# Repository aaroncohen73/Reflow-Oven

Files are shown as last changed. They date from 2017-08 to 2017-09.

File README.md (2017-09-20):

# Code and Design files for Solder Reflow Toaster Oven

The code (available inside `code/`) is licensed under the
[GNU General Public License, version 3](https://www.gnu.org/licenses/gpl.html), and
the PCB design (available inside `design/`) is licensed under the
[Creative Commons ShareAlike 4.0 International](https://creativecommons.org/licenses/by-sa/4.0/) license.

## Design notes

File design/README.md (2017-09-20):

# EAGLE CAD Design Files for Solder Reflow Toaster Oven

This design is compatible with EAGLE 8.2+

This design is licensed under the [Creative Commons ShareAlike 4.0 International](https://creativecommons.org/licenses/by-sa/4.0/) license.

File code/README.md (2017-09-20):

# Code for Solder Reflow Toaster Oven

The code in this subdirectory is available under the [GNU General Public License, version 3](https://www.gnu.org/licenses/gpl.html).

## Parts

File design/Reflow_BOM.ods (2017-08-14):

Reference | Digikey Part Number | Manufacturer | Description | Function
U1 | ATMEGA328-AU-ND | Microchip | ATmega328 Microcontroller, 28DIP | Oven controller
U2 | 768-1135-1-ND | FTDI | FT230XS-R USB to UART bridge, 16SSOP | USB control interface
U3 | LM3940IT-3.3/NOPB-ND | TI | Linear Voltage Regulator, 3.3V, 1A, TO-220 | 3.3V regulator
H1 | S6106-ND | Sullins | Female DIP Header 2x10 | Display cable header
H2 | A123836-ND | TE | 2 Position Screwless Terminal Block | Thermocouple connector
H3 | A123836-ND | TE | 2 Position Screwless Terminal Block | SSR connector
Q1 | IRF9610PBF-ND | Vishay | P-Channel MOSFET, 200V, 1.8A, 20W, TO-220 | Reverse polarity protection
Q2 | 2N7000TACT-ND | ON Semiconductor | N-Channel MOSFET, 60V, 200mA, 400mW, TO-92 | SSR switch
J1 | CP-202B-ND | CUI Inc. | DC Power Barrel Connector, Through Hole | DC power jack
J2 | ED2982-ND | On Shore Technology | USB Type B Connector, Through Hole | USB connector
C1 | 493-12980-1-ND | Nichicon | 0.47uF Electrolytic Capacitor, 200V, Through Hole 5mm | LDO 5V decoupling
C2 | 493-5358-1-ND | Nichicon | 33uF Electrolytic Capacitor, 200V, Through Hole 5mm | LDO 3.3V decoupling
C3 | 493-1826-ND | Nichicon | 470uF Electrolytic Capacitor, 200V, Through Hole 5mm | Display VDD decoupling
C4 | BC1009CT-ND | Vishay | 47pF Capacitor, 50V, Through Hole 5mm | USB D+ noise filter
C5 | BC1009CT-ND | Vishay | 47pF Capacitor, 50V, Through Hole 5mm | USB D- noise filter
R1 | CF14JT4K70CT-ND | Stackpole | 4.7k Resistor, 1/4W, Through Hole 5mm | USB sense voltage divider
R2 | CF14JT10K0CT-ND | Stackpole | 10k Resistor, 1/4W, Through Hole 5mm | USB sense voltage divider
R3 | CF14JT27R0CT-ND | Stackpole | 27 Ohm Resistor, 1/4W, Through Hole 5mm | USB D+ noise filter
R4 | CF14JT27R0CT-ND | Stackpole | 27 Ohm Resistor, 1/4W, Through Hole 5mm | USB D- noise filter
R5 | CF14JT270RCT-ND | Stackpole | 270 Ohm Resistor, 1/4W, Through Hole 5mm | TX LED current limiter
R6 | CF14JT270RCT-ND | Stackpole | 270 Ohm Resistor, 1/4W, Through Hole 5mm | RX LED current limiter
R7 | CF14JT270RCT-ND | Stackpole | 270 Ohm Resistor, 1/4W, Through Hole 5mm | SSR current limiter
R8 | CF14JT270RCT-ND | Stackpole | 270 Ohm Resistor, 1/4W, Through Hole 5mm | Power LED current limiter
D1 | 160-1677-ND | Lite-On | Green LED, 2.1V, Through Hole 5mm | UART TX LED
D2 | 160-1686-ND | Lite-On | Yellow LED, 2.05V, Through Hole 5mm | UART RX LED
D3 | 160-1677-ND | Lite-On | Green LED, 2.1V, Through Hole 5mm | Power LED
FB1 | 240-2378-1-ND | Laird | Ferrite Bead, 1k @ 100MHz, 0603 | Thermocouple noise filter
FB2 | 240-2378-1-ND | Laird | Ferrite Bead, 1k @ 100MHz, 0603 | Thermocouple noise filter
- | 255-2978-ND | Panasonic | AQA221VL Solid State Relay, Screw Terminals | Oven power relay
- | 255-2665-ND | Panasonic | AQP-HS-30/40A Heatsink for Solid State Relay | Relay heatsink
- | NHD-1.69-160128UGC3-ND | Newhaven Display | OLED Display, 160x128, 1.69”, 3-Wire SPI | Status display
- | 1286-1099-ND | Digilent | Thermocouple Type K, 1m | Temperature sensor
- | 1175-1661-ND | CNC Tech | Ribbon Cable Male DIP Header 2x10 | Display cable header
- | 1175-1661-ND | CNC Tech | Ribbon Cable Male DIP Header 2x10 | Display cable header
- | S6106-ND | Sullins | Female DIP Header 2x10 | Display cable header

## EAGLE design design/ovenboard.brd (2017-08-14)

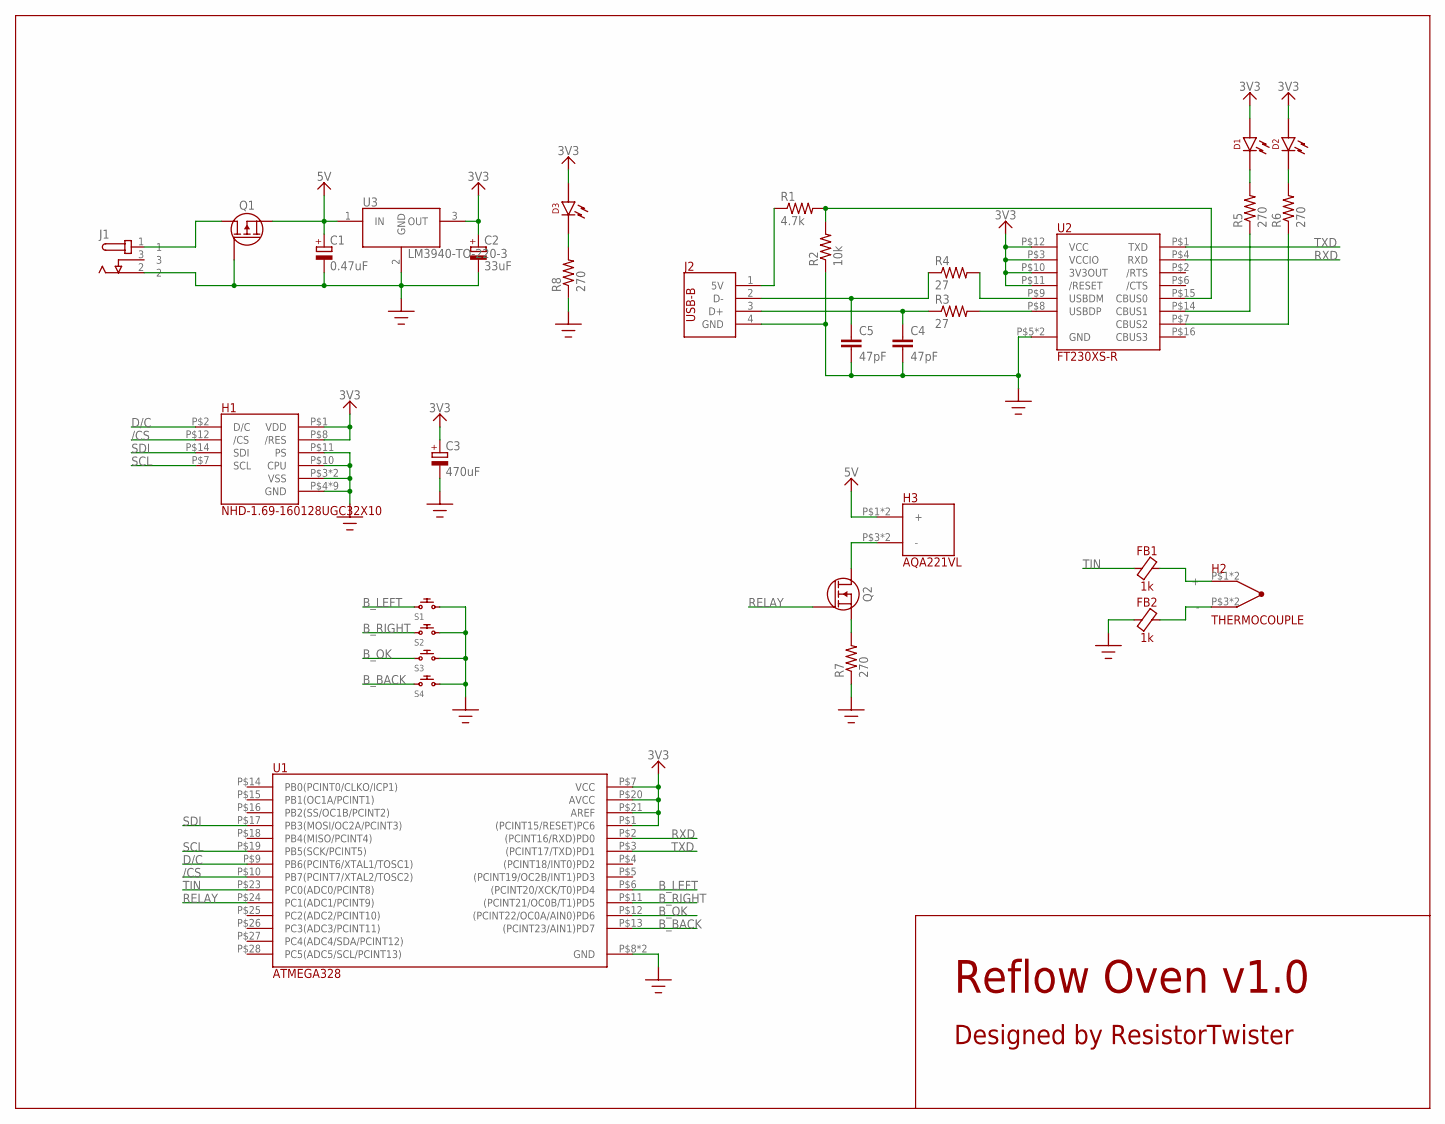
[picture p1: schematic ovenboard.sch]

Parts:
C1: 0.47uF; E5-5
C2: 33uF; E5-5
C3: 470uF; E5-5
C4, C5: 47pF; C050-024X044
D1, D2, D3: LED-5; LED5
FB1, FB2: 1k; 0603
H1: NHD-1.69-160128UGC32X10; 2X10HEADER0.1
H2: THERMOCOUPLE; 2TERMINAL
H3: AQA221VL; 2TERMINAL
J1: PJ-202B
J2: USB2.0-B1HSW6; B1HSW6
Q1: MOSFET-P-TO-220-3; TO-220-3
Q2: MOSFET-N-TO-92; TO-92
R1: 4.7k; 0204/5
R2: 10k; 0204/5
R3, R4: 27; 0204/5
R5, R6, R7, R8: 270; 0204/5
S1, S2, S3, S4: PUSHBUTTON; 1X2HEADER0.1
U1: ATMEGA328; 28DIP0.1
U2: FT230XS-R; 16SSOP0.025
U3: LM3940-TO-220-3; TO-220-3

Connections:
3V3: C2.+, C3.+, D1.A, D2.A, D3.A, H1.P$1 (VDD), H1.P$8 (/RES), U1.P$1 ((PCINT15/RESET)PC6), U1.P$7 (VCC), U1.P$20 (AVCC), U1.P$21 (AREF), U2.P$3 (VCCIO), U2.P$10 (3V3OUT), U2.P$11 (/RESET), U2.P$12 (VCC), U3.3 (OUT)
5V: C1.+, H3.P$1 (+), H3.P$2 (+), Q1.2 (S), U3.1 (IN)
/CS: H1.P$12 (/CS), U1.P$10 (PB7(PCINT7/XTAL2/TOSC2))
B_BACK: S4.2, U1.P$13 ((PCINT23/AIN1)PD7)
B_LEFT: S1.2, U1.P$6 ((PCINT20/XCK/T0)PD4)
B_OK: S3.2, U1.P$12 ((PCINT22/OC0A/AIN0)PD6)
B_RIGHT: S2.2, U1.P$11 ((PCINT21/OC0B/T1)PD5)
D/C: H1.P$2 (D/C), U1.P$9 (PB6(PCINT6/XTAL1/TOSC1))
GND: C1.-, C2.-, C3.-, C4.2, C5.2, FB2.1, H1.P$3 (VSS), H1.P$4 (GND), H1.P$5 (GND), H1.P$6 (GND), H1.P$9 (GND), H1.P$10 (CPU), H1.P$11 (PS), H1.P$13 (GND), H1.P$15 (GND), H1.P$16 (GND), H1.P$17 (GND), H1.P$18 (VSS), H1.P$20 (GND), J1.2, J2.4 (GND), Q1.1 (G), R2.1, R7.1, R8.1, S1.1, S2.1, S3.1, S4.1, U1.P$8 (GND), U1.P$22 (GND), U2.P$5 (GND), U2.P$13 (GND), U3.2 (GND)
unnamed: J1.1, Q1.3 (D)
unnamed: R3.2, U2.P$8 (USBDP)
unnamed: C5.1, J2.2 (D-), R4.1
unnamed: C4.1, J2.3 (D+), R3.1
unnamed: J2.1 (5V), R1.1
unnamed: R1.2, R2.2, U2.P$15 (CBUS0)
unnamed: R5.1, U2.P$14 (CBUS1)
unnamed: R6.1, U2.P$7 (CBUS2)
unnamed: R4.2, U2.P$9 (USBDM)
unnamed: D1.C, R5.2
unnamed: D2.C, R6.2
unnamed: FB1.2, H2.P$1 (+), H2.P$2 (+)
unnamed: FB2.2, H2.P$3 (-), H2.P$4 (-)
unnamed: H3.P$3 (-), H3.P$4 (-), Q2.3 (D)
unnamed: D3.C, R8.2
unnamed: Q2.1 (S), R7.2
RELAY: Q2.2 (G), U1.P$24 (PC1(ADC1/PCINT9))
RXD: U1.P$2 ((PCINT16/RXD)PD0), U2.P$4 (RXD)
SCL: H1.P$7 (SCL), U1.P$19 (PB5(SCK/PCINT5))
SDI: H1.P$14 (SDI), U1.P$17 (PB3(MOSI/OC2A/PCINT3))
TIN: FB1.1, U1.P$23 (PC0(ADC0/PCINT8))
TXD: U1.P$3 ((PCINT17/TXD)PD1), U2.P$1 (TXD)

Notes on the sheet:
Reflow Oven v1.0
Designed by ResistorTwister

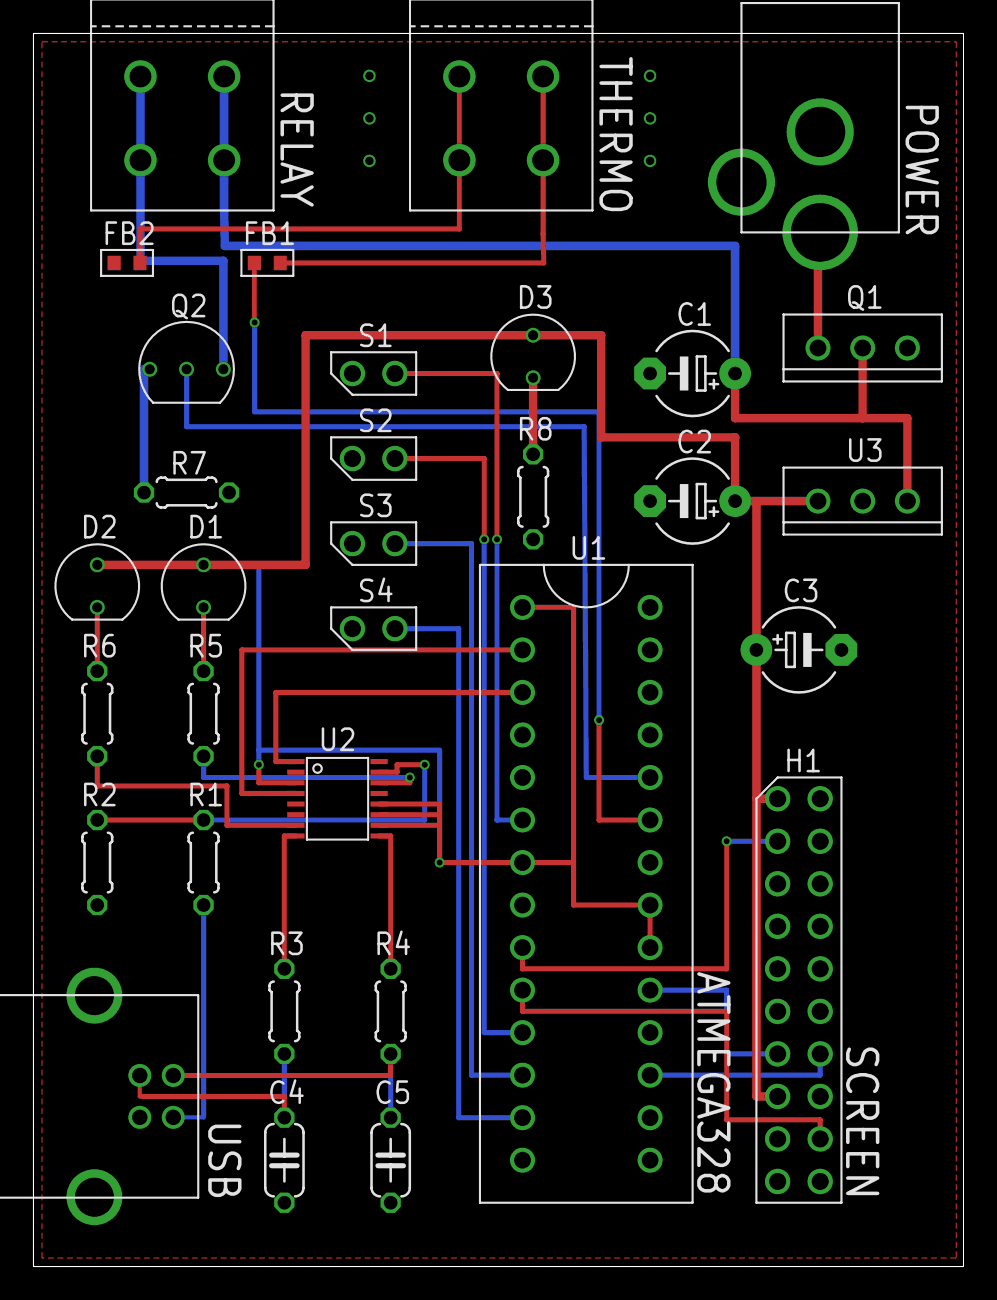
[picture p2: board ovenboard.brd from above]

Board: 2 copper layers, 55.5 x 73.7 mm, 32 parts (0 on the bottom side), 31 nets.

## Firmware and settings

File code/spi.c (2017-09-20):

/* spi.c - SPI master interface
 *
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
 * You should have received a copy of the GNU General Public License
 * along with this program.  If not, see <http://www.gnu.org/licenses/>. */

#include <stdint.h>
#include <avr/io.h>
#include "spi.h"


enum ChipSelect { CS_OFF, CS_ON };

static void _spi_cs(uint8_t slave, enum ChipSelect state)
{
    uint8_t pin;

    switch (slave)
    {
        case SPI_SLAVE_SCREEN:
            pin = PC0;
            break;
        case SPI_SLAVE_TCOUPLE:
            pin = PC1;
            break;
        default:
            return;
    }

    if (state == CS_ON)
        PORTC &= ~_BV(pin);
    else
        PORTC |= _BV(pin);
}

/* Initialize the SPI interface. */
void spi_init(void)
{
    /* Enable SPI master mode, idle SCK low, sample on leading edge */
    SPCR |= _BV(SPE) | _BV(MSTR);

    /* f_sck = f_osc/2 (5 MHz) */
    SPSR |= _BV(SPI2X);

    /* Enable slave select pins */
    DDRC |= _BV(PC0) | _BV(PC1);
    PORTC |= _BV(PC0) | _BV(PC1);
}

/* Write data to a SPI slave */
void spi_write(uint8_t slave, uint8_t *data, uint16_t count)
{
    _spi_cs(slave, CS_ON);

    for (uint16_t i = 0; i < count; i++)
    {
        SPDR = data[i];

        while (!(SPSR & _BV(SPIF)));
    }

    _spi_cs(slave, CS_OFF);
}

/* Read data from a SPI slave */
void spi_read(uint8_t slave, uint8_t *data, uint16_t count)
{
    _spi_cs(slave, CS_ON);

    for (uint16_t i = 0; i < count; i++)
    {
        while (!(SPSR & _BV(SPIF)));

        data[i] = SPDR;
    }

    _spi_cs(slave, CS_OFF);
}

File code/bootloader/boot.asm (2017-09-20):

; boot.s - Minimal bootloader with firmware update over FT230X USB to UART
; 
; This program is free software: you can redistribute it and/or modify
; it under the terms of the GNU General Public License as published by
; the Free Software Foundation, either version 3 of the License, or
; (at your option) any later version.
;
; This program is distributed in the hope that it will be useful,
; but WITHOUT ANY WARRANTY; without even the implied warranty of
; MERCHANTABILITY or FITNESS FOR A PARTICULAR PURPOSE.  See the
; GNU General Public License for more details.
;
; You should have received a copy of the GNU General Public License
; along with this program.  If not, see <http://www.gnu.org/licenses/>.

.nolist
.include "m328def.inc"
.list

.equ F_OSC 8000000		; 8 MHz clock

.equ BOOTLOADER_INTERRUPT 0xFF	; Interrupt byte sent to ATMega during reset sequence that starts the bootloader
.equ BOOTLOADER_READY     0x55  ; Byte sent over UART signifying the device has acknowledged the interrupt

.equ BOOTLOADER_INT_WAIT 20	; Wait 20 ms for bootloader interrupt symbol

.org THIRDBOOTSTART		; Bootloader section start at 0x3c00

rjmp boot_main			; Start the bootloader

boot_main:

	; Initialize stack pointer at the end of RAM space
	ldi R24, low(RAMEND)
	ldi R25, high(RAMEND)
	out SPL, R24
	out SPH, R25

	; Turn off unused peripherals to reduce power consumption
	ldi R24, (1<<PRTWI)|(1<<PRTIM2)|(1<<PRADC)
	sts PRR, R24

	; Initialize UART0
	ldi R24, (1<<RXEN0)|(1<<TXEN0)	; Enable RX and TX
	sts UCSR0B, R24

	ldi R24, (1 << UPM01)		; Enable even parity bit check
	sts UCSR0C, R24

	ldi R24, 25			; Set baud rate to 19.2 kbps
	sts UBRR0L, R24

	ldi R23, BOOTLOADER_INT_WAIT

checkl: rcall wait1			; Delay for 1 millisecond

	lds R24, UCSR0A			; Check for UART0 RX Complete flag
	sbrs R24, RXC0			; If UART0 RX Complete not set, go to next loop iteration
	rjmp decl

	lds R24, UDR0			; Load contents of UART0 data register
	cpi R24, BOOTLOADER_INTERRUPT	; Check for interrupt byte
	breq bootloader_start		; If interrupt byte recieved, start the bootloader

decl:	dec R23
	cpi R23, 0			; If wait time is up without recieving bootloader interrupt, start main
	breq FLASHEND+1			; program execution (FLASHEND + 1 = Address 0x0000)

	rjmp checkl			; If wait time is not up yet, go to next loop iteration

boot_start:
	ldi R16, BOOTLOADER_READY	; Send READY byte back on UART0
	rcall uart_tx_single

	rcall uart_rx_single		; Grab single byte from UART0 and repeat it back
	rcall uart_tx_single

	rjmp FLASHEND+1

uart_tx_single:
	lds R24, UCSR0A			; Wait for UART0 transmit buffer to be empty
	sbrs R24, UDRE0
	rjmp uart_tx_single

	sts UDR0, R16			; Store byte to be sent in UART0 data register
	ret

uart_rx_single:
	lds R24, UCSR0A			; Wait for UART0 RX Complete flag
	sbrs R24, RXC0
	rjmp uart_rx_single

	lds R16, UDR0			; Store received byte
	ret

wait1:
	ldi R24, (1<<CS11)		; Set TIMER1 clock source = I/O clock / 8 (1 MHz)
	sts TCCR1B, R24

	ldi R24, 0xE8			; Set TIMER1 compare value to 1000 cycles (1 ms)
	ldi R25, 0x03
	sts OCR1AL, R24
	sts OCR1AH, R25

	ldi R24, 0x00			; Reset timer
	sts TCNT1H, R24
	sts TCNT1L, R24

	ldi R24, (1<<OCF1A)		; Reset output compare flag
	out TIFR1, R24

checkw:	sbis TIFR1, OCF1A		; Loop until output compare flag is set
	rjmp checko

	ret

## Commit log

2017-08-14 Design and board layout
    [Reflow_BOM.ods, ovenboard.brd, ovenboard.sch]
2017-09-12 Add FontTool and SPI interface
